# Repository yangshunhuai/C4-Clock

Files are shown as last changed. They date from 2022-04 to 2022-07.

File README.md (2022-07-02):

# C4 Clock
自制能爆炸的C4闹钟，再也不怕闹钟叫不醒了（不是

## 介绍
普通的闹钟是叫不醒我这种睡着了就叫不醒的人的，即便声音再响也没用。但是，最近收到了一个新的闹钟，响起来非常像定时炸弹。想到游戏CS:GO里面有一个C4炸弹，可以以它为原型，制作一个C4形状的闹钟，响的时候也像C4那样，就可以很轻易地叫醒人了。

1. 当闹钟响起来之后，必须在30秒内按下键盘上的确认键，否则炸弹里的一个电解电容就会爆炸（当然放个小烟花也是可以的，但是上海弄不到烟花，并且这样的话壳子就不能重复利用了）。
2. 然后屏幕上会有5道数学计算题，每一题15秒，超过时间会爆炸。

## 硬件
MCU采用了乐鑫ESP32-WROOM-32D，支持WiFi+蓝牙，可以自动同步时间，支持通过web端设置闹钟。

PCB文件放在Hardware文件夹下。
> 原理图的J4处是一个直流升压模块，淘宝上有卖的，可以在[这里](https://detail.tmall.com/item.htm?id=41345069371)买到
> 
> 规格如下：
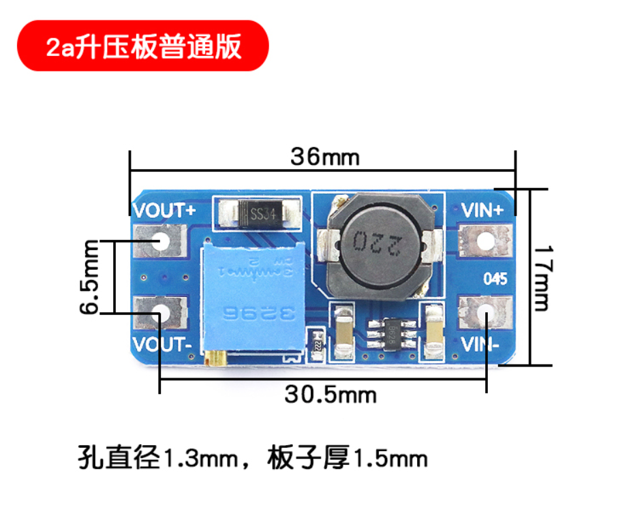
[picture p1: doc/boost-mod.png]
> 
>
> 安装的时候，主板上有对应的四个焊盘，直接一大坨锡糊在四个焊盘上，反正能连上就行了。

## 软件
鉴于Arduino自己的IDE功能太少，不能自动补全也不能单步调试~~我要这废物有何用~~所以想办法弄了一个VS插件（visual micro），可以支持arduino

## 灵感
芜狐ー起飞@bilibili的[计算练习器](https://www.bilibili.com/video/BV1YU4y1j7n4)

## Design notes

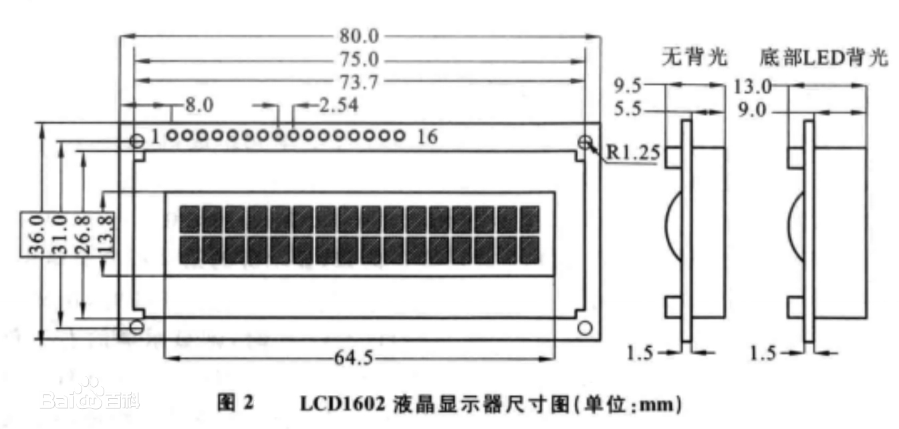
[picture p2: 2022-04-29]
doc/lcd1602.jpg

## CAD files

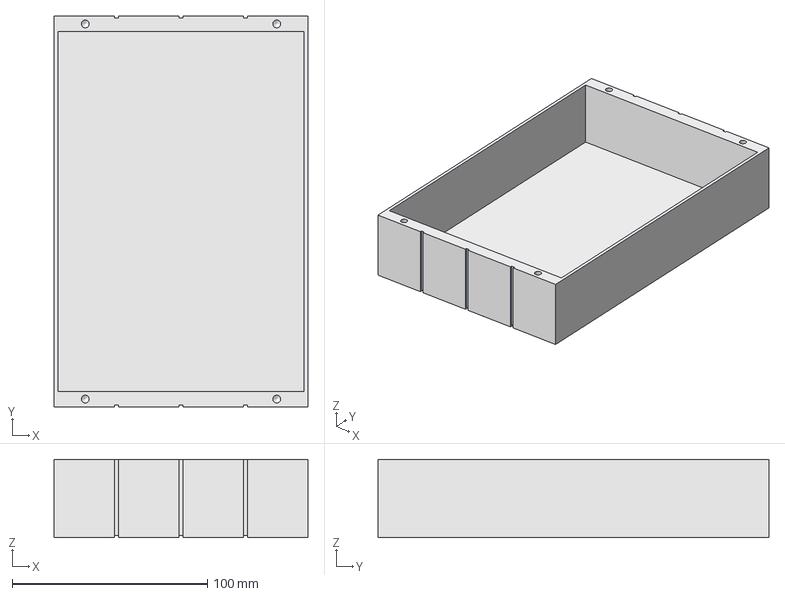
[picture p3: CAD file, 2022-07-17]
hardware/3d-model/C4-Clock.FCStd
130.0 x 200.0 x 40.0 mm

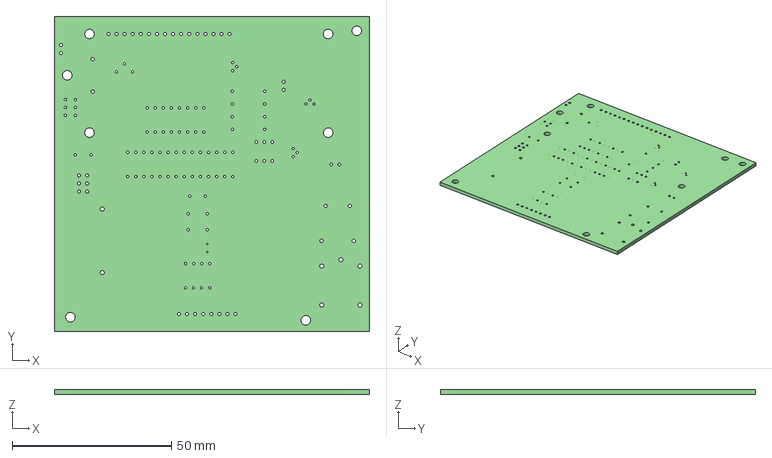
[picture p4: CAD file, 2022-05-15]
hardware/kicad/C4-Clock.step
99.0 x 99.0 x 1.60 mm

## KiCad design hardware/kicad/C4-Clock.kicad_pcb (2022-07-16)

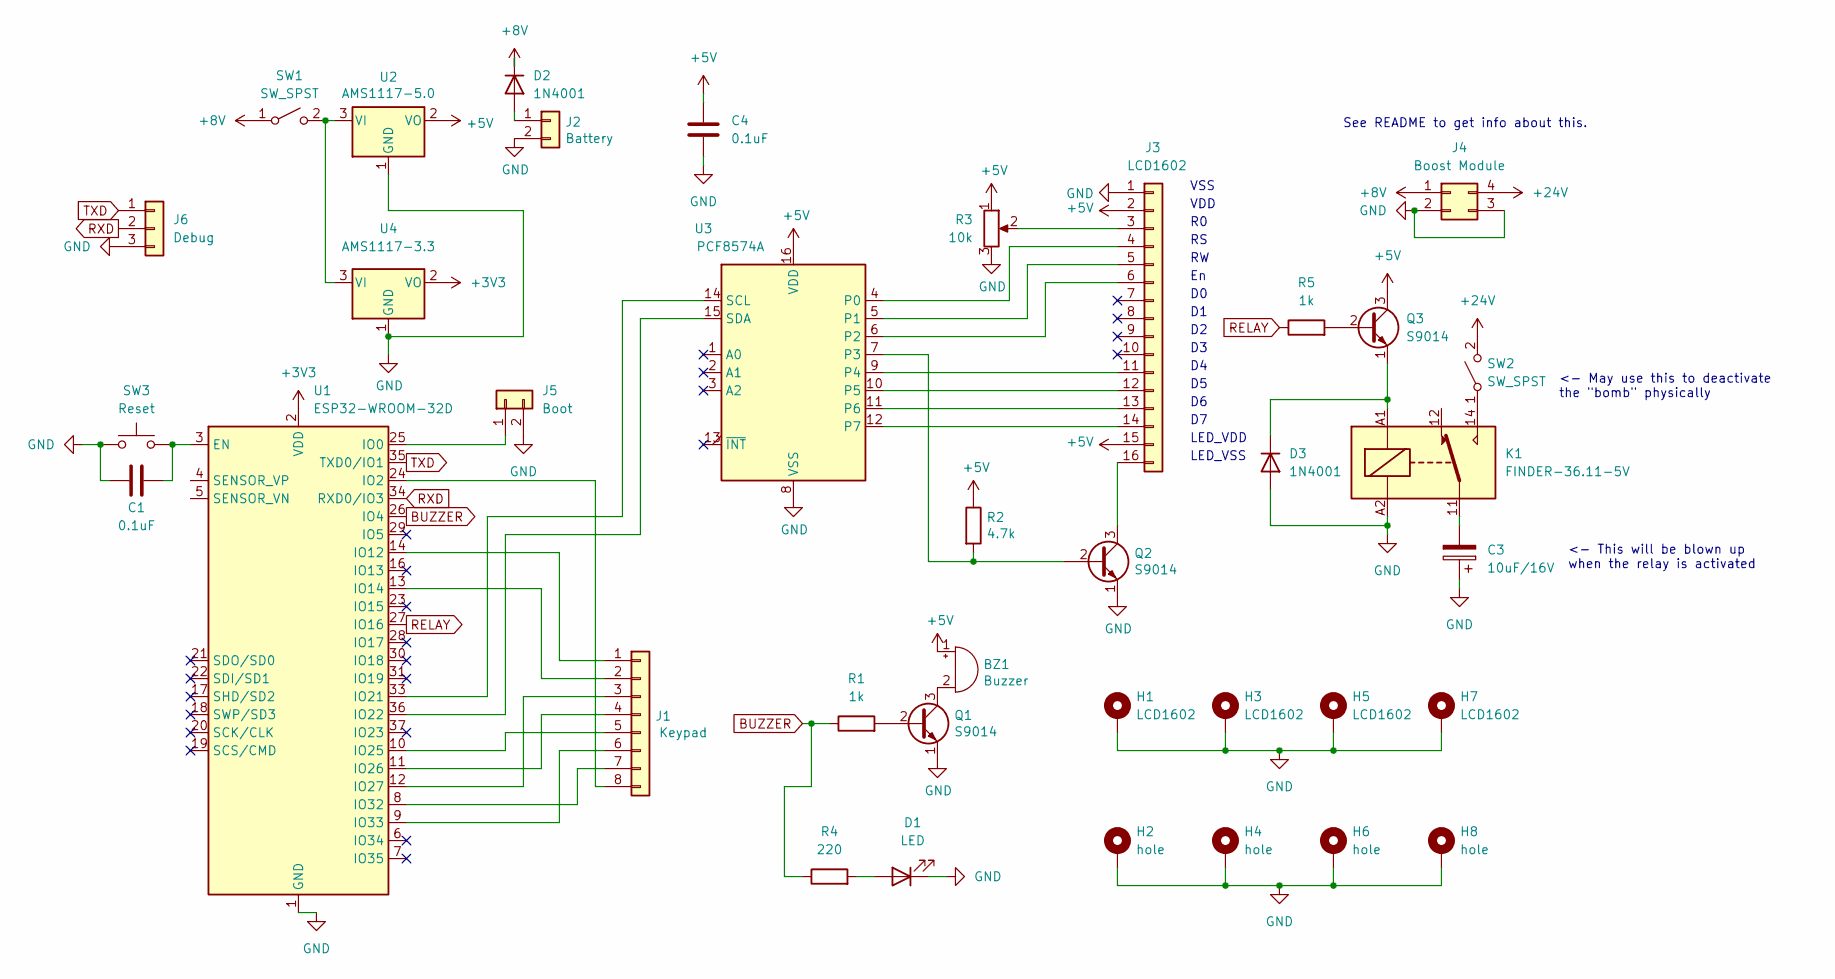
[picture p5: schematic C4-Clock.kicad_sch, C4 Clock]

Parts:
BZ1: Buzzer; Buzzer_12x9.5RM7.6
C1, C4: 0.1uF; C_Disc_D4.3mm_W1.9mm_P5.00mm
C3: 10uF/16V; PinSocket_1x02_P2.54mm_Vertical
D1: LED; LED_D5.0mm
D2, D3: 1N4001; D_DO-41_SOD81_P10.16mm_Horizontal
H1, H3, H5, H7: LCD1602; MountingHole_3mm_Pad_TopBottom
H2, H4, H6, H8: hole; MountingHole_3mm_Pad_TopBottom
J1: Keypad; PinHeader_1x08_P2.54mm_Vertical
J2: Battery; PinHeader_1x02_P2.54mm_Horizontal
J3: LCD1602; PinSocket_1x16_P2.54mm_Vertical
J4: Boost Module; DC-Buck-2A
J5: Boot; PinHeader_1x02_P2.54mm_Vertical
J6: Debug; PinHeader_1x03_P2.54mm_Vertical
K1: FINDER-36.11-5V; Relay_SPDT_Finder_36.11
Q1, Q2, Q3: S9014; TO-92
R1, R5: 1k; R_Axial_DIN0207_L6.3mm_D2.5mm_P10.16mm_Horizontal
R2: 4.7k; R_Axial_DIN0207_L6.3mm_D2.5mm_P10.16mm_Horizontal
R3: 10k; Potentiometer_Vishay_T73YP_Vertical
R4: 220; R_Axial_DIN0207_L6.3mm_D2.5mm_P10.16mm_Horizontal
SW1: SW_SPST; SW_E-Switch_EG1271_DPDT
SW2: SW_SPST; SW_Push_2P2T_Toggle_CK_PVA2xxH1xxxxxxV2
SW3: Reset; SW_PUSH_6mm_H5mm
U1: ESP32-WROOM-32D; ESP32-WROOM-32
U2: AMS1117-5.0; SOT-223-3_TabPin2
U3: PCF8574A; DIP-16_W7.62mm_Socket
U4: AMS1117-3.3; SOT-223-3_TabPin2

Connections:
+3V3: U1.2 (VDD), U4.2 (VO)
+5V: BZ1.1 (-), C4.1, J3.2, J3.15, Q3.3 (C), R2.1, R3.1, U2.2 (VO), U3.16 (VDD)
+8V: D2.1 (K), J4.1, SW1.1 (A)
+24V: J4.4, SW2.2 (B)
BUZZER: R1.1, R4.1, U1.26 (IO4)
GND: C1.1, C3.1, C4.2, D1.1 (K), D3.2 (A), H1.1, H2.1, H3.1, H4.1, H5.1, H6.1, H7.1, H8.1, J2.2, J3.1, J4.2, J4.3, J5.2, J6.3, K1.A2, Q1.1 (E), Q2.1 (E), R3.3, SW3.1, U1.1 (GND), U1.15 (GND), U1.38 (GND), U1.39 (GND), U2.1 (GND), U3.8 (VSS), U4.1 (GND)
unnamed: BZ1.2 (+), Q1.3 (C)
unnamed: C1.2, SW3.2, U1.3 (EN)
unnamed: C3.2, K1.11
unnamed: D1.2 (A), R4.2
unnamed: D2.2 (A), J2.1
unnamed: D3.1 (K), K1.A1, Q3.1 (E)
unnamed: J1.1, U1.14 (IO12)
unnamed: J1.2, U1.13 (IO14)
unnamed: J1.3, U1.12 (IO27)
unnamed: J1.4, U1.11 (IO26)
unnamed: J1.5, U1.10 (IO25)
unnamed: J1.6, U1.9 (IO33)
unnamed: J1.7, U1.8 (IO32)
unnamed: J1.8, U1.24 (IO2)
unnamed: J3.3, R3.2
unnamed: J3.4, U3.4 (P0)
unnamed: J3.5, U3.5 (P1)
unnamed: J3.6, U3.6 (P2)
unnamed: J3.11, U3.9 (P4)
unnamed: J3.12, U3.10 (P5)
unnamed: J3.13, U3.11 (P6)
unnamed: J3.14, U3.12 (P7)
unnamed: J3.16, Q2.3 (C)
unnamed: J5.1, U1.25 (IO0)
unnamed: K1.14, SW2.1 (A)
unnamed: Q1.2 (B), R1.2
unnamed: Q2.2 (B), R2.2, U3.7 (P3)
unnamed: Q3.2 (B), R5.2
unnamed: SW1.2 (B), U2.3 (VI), U4.3 (VI)
unnamed: U1.33 (IO21), U3.14 (SCL)
unnamed: U1.36 (IO22), U3.15 (SDA)
RELAY: R5.1, U1.27 (IO16)
RXD: J6.2, U1.34 (RXD0/IO3)
TXD: J6.1, U1.35 (TXD0/IO1)

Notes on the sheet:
VSS
<- May use this to deactivate the "bomb" physically
VDD
LED_VDD
See README to get info about this.
LED_VSS
<- This will be blown up when the relay is activated

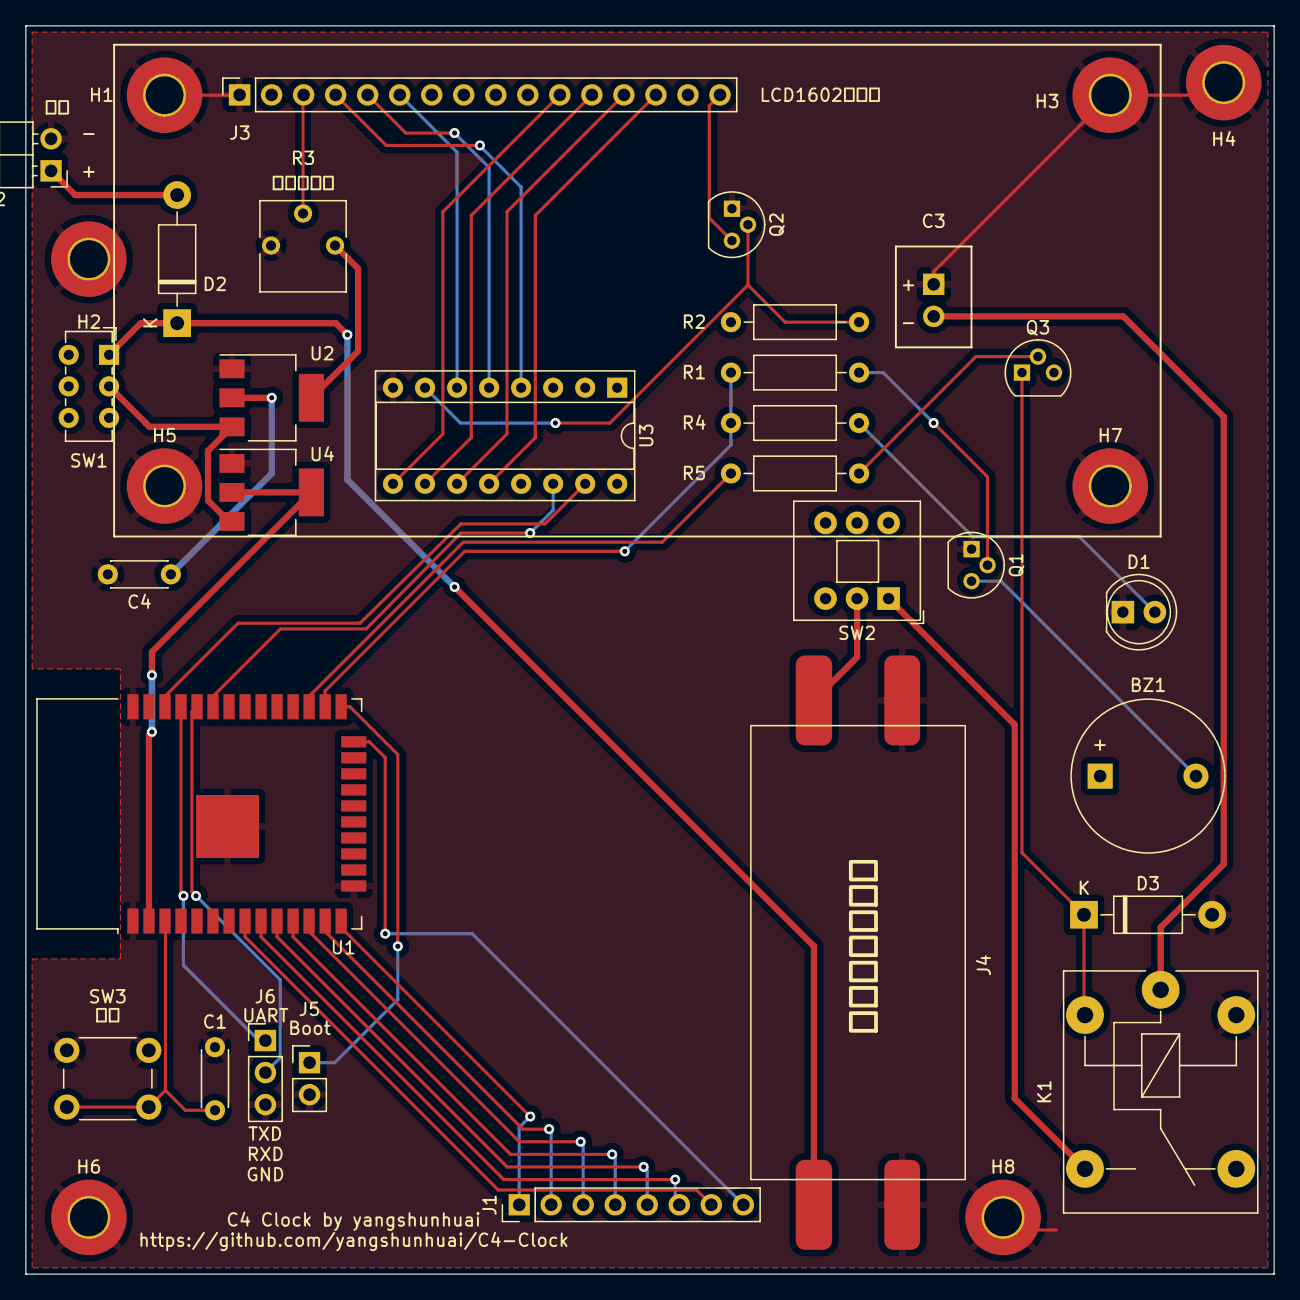
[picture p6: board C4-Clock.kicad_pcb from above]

Board: 2 copper layers, 99.0 x 99.0 mm, 37 parts (1 on the bottom side), 40 nets.

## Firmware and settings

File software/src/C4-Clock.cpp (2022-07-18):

/*
 Name:		C4_Clock.ino
 Created:	2022/5/4 21:56:00
 Author:	Michael
*/

#include "C4-Clock.h"
#include "Alarm.h"
#include "Time1.h"
#include "Network.h"
#include "MainMenu.h"
#include "Settings.h"
#include "PeriphControl.h"

unsigned long lastmillis;
char ntpServer[] = "ntp1.aliyun.com";
bool alarmIsOff = false;

char keys[ROWS][COLS] = {
  {'1','2','3','A'},
  {'4','5','6','B'},
  {'7','8','9','C'},
  {'*','0','#','D'}
};
byte rowPins[ROWS] = { 14, 27, 26, 25 }; //connect to the row pinouts of the keypad
byte colPins[COLS] = { 33, 32, 2, 17 }; //connect to the column pinouts of the keypad
Adafruit_Keypad keypad = Adafruit_Keypad(makeKeymap(keys), rowPins, colPins, ROWS, COLS);
LiquidCrystal_I2C lcd(LCD1602_ADDR, 16, 2);
ESP32Time rtc(GMT_OFFSET);

// the setup function runs once when you press reset or power the board
void setup() {
	// Device initialization
	Serial.begin(SER_BAUD);
	Serial.println("Serial communication begun");
	// Pin initialization
	pinMode(RELAY, OUTPUT);
	pinMode(BUZZER, OUTPUT);
	digitalWrite(RELAY, LOW);
	Serial.println("GPIO init completed");
	//keypad.begin();
	Serial.println("Keypad init completed");
	
	lcd.init();
	lcd.backlight();
	Serial.println("LCD init completed");
	lcd.setCursor(4, 0);
	lcd.print("C4 Clock");
	lcd.setCursor(0, 1);
	lcd.print("by yangshunhuai");
	digitalWrite(BUZZER, HIGH);
	delay(100);
	digitalWrite(BUZZER, LOW);
	delay(1000);
	lcd.clear();
	lcd.setCursor(0, 0);
	lcd.print("Configuring net");
	lcd.setCursor(0, 1);
	lcd.print("work");
	setupNetwork();
	Serial.println("Network init completed");

	lastmillis = millis();
}

// the loop function runs over and over again until power down or reset
void loop() {
	Serial.println("Testing keypad");
	keypad.tick();
	if (keypad.available()) {
		keypadEvent e = keypad.read();
		if (e.bit.KEY == 'A' && e.bit.EVENT == KEY_JUST_RELEASED) {
			beep();
			settings();
		}
	}

	unsigned long curmillis = millis();
	if ((curmillis - lastmillis) >= 1000) {
		updateTime();
		checkAlarm();
		lastmillis = curmillis;
	}
}

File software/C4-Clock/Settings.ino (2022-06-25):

/*
About configuration persistence:
  Item                    Address       Data type  Length
- Alarm hour              1             int        1 byte
- Alarm minute            2             int        1 byte
- Alarm repeat mode       3             int        1 byte
- C3 Explosion            4             bool       1 bit
*/

#define ALARM_HOUR_ADDR 1
#define ALARM_MINUTE_ADDR 2
#define ALARM_REPEAT_ADDR 3
#define C_EXP_ADDR 4

void settings() {
	beep();
	lcd.clear();
	lcd.setCursor(0, 0);
	lcd.print("1.S-Alm 2.S-time");
	lcd.setCursor(0, 1);
	lcd.print("3.S-Eff 4.About");
	char key = waitForKeypad();
	Serial.println(key);
	switch (key)
	{
	default:
		break;
	case '1':
		setAlarm();
		break;
	case '2':
		setTime();
		break;
	case '3':
		setEffect();
		break;
	case '4':
		about();
		break;
	case '9':
		resetConfig();
		break;
	case 'D':
		break;
	}
}

void setAlarm() {
	beep();
	Serial.println("Entering setAlarm");

	struct alarmConfig alarmcfg{};

	lcd.clear();
	lcd.setCursor(4, 0);
	lcd.print("Set Hour");
	lcd.setCursor(6, 1);
	lcd.print(">  <");
	alarmcfg.hour = getIntFromKeypad(2, 1, 7);
	delay(1000);

	lcd.clear();
	lcd.setCursor(4, 0);
	lcd.print("Set Minute");
	lcd.setCursor(6, 1);
	lcd.print(">  <");
	alarmcfg.minute = getIntFromKeypad(2, 1, 7);
	delay(1000);

	lcd.clear();
	lcd.setCursor(0, 0);
	lcd.print("1.Mo-Fr  2.Sa-Su");
	lcd.setCursor(0, 1);
	lcd.print("3.All  > <");
	alarmcfg.repeat = getIntFromKeypad(1, 1, 8);
	delay(1000);

	lcd.clear();
	lcd.setCursor(3, 0);
	lcd.print("Alarm set");

	saveAlarmCfg(&alarmcfg);
}

void setTime() {
	Serial.println("Entering setTime");
	beep();

	struct timeConfig timecfg{};

	lcd.clear();
	lcd.setCursor(4, 0);
	lcd.print("Set Year");
	lcd.setCursor(5, 1);
	lcd.print(">    <");
	timecfg.year = getIntFromKeypad(4, 1, 6);
	delay(1000);

	lcd.clear();
	lcd.setCursor(4, 0);
	lcd.print("Set Month");
	lcd.setCursor(6, 1);
	lcd.print(">  <");
	timecfg.month = getIntFromKeypad(2, 1, 7);
	delay(1000);

	lcd.clear();
	lcd.setCursor(4, 0);
	lcd.print("Set Day");
	lcd.setCursor(6, 1);
	lcd.print(">  <");
	timecfg.day = getIntFromKeypad(2, 1, 7);
	delay(1000);

	lcd.clear();
	lcd.setCursor(4, 0);
	lcd.print("Set Hour");
	lcd.setCursor(6, 1);
	lcd.print(">  <");
	timecfg.hour = getIntFromKeypad(2, 1, 7);
	delay(1000);

	lcd.clear();
	lcd.setCursor(4, 0);
	lcd.print("Set Minute");
	lcd.setCursor(6, 1);
	lcd.print(">  <");
	timecfg.minute = getIntFromKeypad(2, 1, 7);
	delay(1000);

	saveTimeCfg(&timecfg);
	lcd.clear();
	lcd.setCursor(3, 0);
	lcd.print("DateTime Set");
	delay(1000);
}

void setEffect() {
	// TODO: 添加设置界面逻辑
	;;
}

void about() {
	// TODO：添加关于界面逻辑
	;;
}

void resetConfig() {
	Serial.println("Entering resetConfig");
	beep();
	lcd.clear();
	lcd.setCursor(1, 0);
	lcd.print("Clear EEPROM?");
	lcd.setCursor(0, 1);
	lcd.print("1. Yes     2. No");
	if (waitForKeypad() == '1') {
		for (int i = 0; i < EEPROM.length(); i++) {
			EEPROM.write(i, 0);
		}
		lcd.clear();
		lcd.setCursor(1, 0);
		lcd.print("EEPROM cleared");
		delay(1000);
	}
	settings();
}

void saveTimeCfg(struct timeConfig* configStruct) {
	RtcDateTime dt = RtcDateTime(configStruct->year, configStruct->month, configStruct->day, configStruct->hour, configStruct->minute, 0);
	rtc.SetDateTime(dt);
}

void getAlarmCfg(struct alarmConfig *configStruct) {
	configStruct->hour = EEPROM.read(ALARM_HOUR_ADDR);
	configStruct->minute = EEPROM.read(ALARM_MINUTE_ADDR);
	configStruct->repeat = EEPROM.read(ALARM_REPEAT_ADDR);
}

void saveAlarmCfg(struct alarmConfig *configStruct) {
	EEPROM.write(ALARM_HOUR_ADDR, configStruct->hour);
	EEPROM.write(ALARM_MINUTE_ADDR, configStruct->minute);
	EEPROM.write(ALARM_REPEAT_ADDR, configStruct->repeat);
}

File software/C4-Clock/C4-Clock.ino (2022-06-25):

/*
 Name:		C4_Clock.ino
 Created:	2022/5/4 21:56:00
 Author:	Michael
*/

#include <EEPROM.h>
#include <Adafruit_Keypad_Ringbuffer.h>
#include <Adafruit_Keypad.h>
#include <ThreeWire.h>
#include <RtcDS1302.h>
#include <LiquidCrystal_I2C.h>

// Pin definitions
#define RELAY A1
#define BUZZER 10
#define LCD1602_ADDR 0x27
#define DS1302_CLK A2
#define DS1302_IO A3
#define DS1302_CE 11

// Device object initialization
#define ROWS 4
#define COLS 4
char keys[ROWS][COLS] = {
  {'1','2','3','A'},
  {'4','5','6','B'},
  {'7','8','9','C'},
  {'*','0','#','D'}
};
byte rowPins[ROWS] = { 2, 3, 4, 5 }; //connect to the row pinouts of the keypad
byte colPins[COLS] = { 6, 7, 8, 9 }; //connect to the column pinouts of the keypad
Adafruit_Keypad keypad = Adafruit_Keypad(makeKeymap(keys), rowPins, colPins, ROWS, COLS);

ThreeWire myWire(DS1302_IO, DS1302_CLK, DS1302_CE); // IO, SCLK, CE
RtcDS1302<ThreeWire> rtc(myWire);

LiquidCrystal_I2C lcd(LCD1602_ADDR, 16, 2);

// Variable declaration
unsigned long lastmillis;
struct alarmConfig {
	int hour;
	int minute;
	int repeat;
};

struct timeConfig {
	int year;
	int month;
	int day;
	int hour;
	int minute;
};

bool alarmIsOff = false;

// the setup function runs once when you press reset or power the board
void setup() {
	// Pin initialization
	pinMode(RELAY, OUTPUT);
	pinMode(BUZZER, OUTPUT);
	digitalWrite(RELAY, LOW);
	// Device initialization
	Serial.begin(9600);
	keypad.begin();
	
	lcd.init();
	lcd.backlight();
	lcd.setCursor(4, 0);
	lcd.print("C4 Clock");
	lcd.setCursor(0, 1);
	lcd.print("by yangshunhuai");
	digitalWrite(BUZZER, HIGH);
	delay(100);
	digitalWrite(BUZZER, LOW);
	// RTC initialization. Time is automatically synchronized to
	// the time this program is built.
	rtc.Begin();
	if (!rtc.IsDateTimeValid())
	{
		// Common Causes:
		//    1) first time you ran and the device wasn't running yet
		//    2) the battery on the device is low or even missing

		Serial.println("RTC lost confidence in the DateTime!");
	}

	if (rtc.GetIsWriteProtected())
	{
		Serial.println("RTC was write protected, enabling writing now");
		rtc.SetIsWriteProtected(false);
	}

	if (!rtc.GetIsRunning())
	{
		Serial.println("RTC was not actively running, starting now");
		rtc.SetIsRunning(true);
	}
	delay(1000);
	lcd.clear();

	// Setup the main menu UpdateTime thread.
	digitalWrite(BUZZER, LOW);

	lastmillis = millis();
}

// the loop function runs over and over again until power down or reset
void loop() {
	keypad.tick();
	if (keypad.available()) {
		keypadEvent e = keypad.read();
		if ((e.bit.KEY == 'A') && (e.bit.EVENT == KEY_JUST_PRESSED)) {
			beep();
			settings();
			beep();
			lcd.clear();
		}
	}

	unsigned long curmillis = millis();
	if ((curmillis - lastmillis) >= 1000) {
		updateTime();
		checkAlarm();
		lastmillis = curmillis;
	}
}

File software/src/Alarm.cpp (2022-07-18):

#include <Arduino.h>
#include "C4-Clock.h"
#include "Time1.h"
#include "Alarm.h"
#include "Settings.h"
#include "PeriphControl.h"

void checkAlarm()
{
	struct timeConfig timecfg;
	struct alarmConfig alarmcfg;
	getTimeCfg(&timecfg);
	getAlarmCfg(&alarmcfg);

	int dayofweek = rtc.getDayofWeek();
	bool isTimeCorrect = (alarmcfg.hour == timecfg.hour) && (alarmcfg.minute == timecfg.minute);
	// Check if today is Monday~Friday
	bool isDayOfWeek1To5 = ((dayofweek == 1) || (dayofweek == 2) || (dayofweek == 3) || (dayofweek == 4) || (dayofweek == 5));
	// Check if today is Saturday~Sunday
	bool isDayOfWeek6To7 = ((dayofweek == 6) || (dayofweek == 0));
	bool isDayCorrect = ((alarmcfg.repeat == 3)							  // Is repeated every day
						 || ((alarmcfg.repeat == 1) && isDayOfWeek1To5)	  // Is repeated Monday~Friday
						 || ((alarmcfg.repeat == 2) && isDayOfWeek6To7)); // Is repeated Saturday~Sunday
	Serial.print("AlarmIsOff is ");
	Serial.println(alarmIsOff);
	if (isTimeCorrect && isDayCorrect && !alarmIsOff)
	{
		lcd.clear();
		lcd.print("Alarm is present");
		while (true)
		{
			beep();
			delay(300);
			keypad.tick();
			if (keypad.available())
			{
				keypadEvent e = keypad.read();
				if (e.bit.EVENT == KEY_JUST_PRESSED)
				{
					Serial.println("Alarm is turned off");
					alarmIsOff = true;
					lcd.clear();
					break;
				}
			}
		}
	}

	if (!isTimeCorrect)
	{
		Serial.println("Setting alarmIsOff to false");
		alarmIsOff = false;
	}
}

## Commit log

2022-04-22 lots of update
    [C4-Clock.kicad_pcb, C4-Clock.kicad_sch]
2022-04-28 Update gitignore to ignore KiCad backup files
2022-04-28 3d-model: Add FreeCAD 3D model
    [C4-Clock.FCStd]
2022-04-28 kicad: create PCB
    [C4-Clock.kicad_pcb, C4-Clock.kicad_sch, C4-Clock.step]
2022-04-29 doc: Add lcd1602 reference
    [C4-Clock.kicad_pcb, C4-Clock.kicad_sch]
2022-05-04 software: Added VS files
    [C4-Clock.kicad_pcb, C4-Clock.kicad_sch, C4-Clock.step]
2022-05-06 hardware: Add parts
    [C4-Clock.kicad_pcb]
2022-05-15 hardware: Update PCB
    [C4-Clock.kicad_pcb, C4-Clock.kicad_sch, C4-Clock.step]
2022-05-15 hardware: Update 3D Model
    [C4-Clock.FCStd]
2022-05-22 3d-model: Added pad for screwholes above
    [C4-Clock.FCStd]
2022-05-22 kicad: prl update
2022-05-22 Removed all hardware files for directory structure fix
    [C4-Clock.FCStd, C4-Clock.kicad_pcb, C4-Clock.kicad_sch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]
2022-05-22 Added hardware files for directory structure fix
    [C4-Clock.FCStd, C4-Clock.kicad_pcb, C4-Clock.kicad_sch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]
2022-06-25 Restructured reset EEPROM logic
    [Settings.ino, Time.ino]
2022-06-25 Fixed unable to turn off alarm bug
    [Alarm.ino, C4-Clock.ino, Settings.ino]
2022-06-26 kicad: Remove unused pin A0
    [C4-Clock.kicad_pcb, C4-Clock.kicad_sch]
2022-07-02 kicad: removed DS1302 and atmega
    [C4-Clock.kicad_sch]
2022-07-16 kicad: Change ATmega328P to ESP32-WROOM-32
    [C4-Clock.kicad_pcb, C4-Clock.kicad_sch]
2022-07-17 software: Completely port VS to PlatformIO
    [C4-Clock.FCStd]
2022-07-18 software: Using Adafruit_Keypad
    [serial-dump.txt]
